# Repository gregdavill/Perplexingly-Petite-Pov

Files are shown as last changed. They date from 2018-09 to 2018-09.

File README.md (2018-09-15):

# Perplexingly-Petite-Pov
A collection of small LED based PCBs.
---

*Current Status: Design Proof of concepts.*

See README of each project to see further details.

---
## idea_001
Based on a Lattice iCE40LP FPGA.
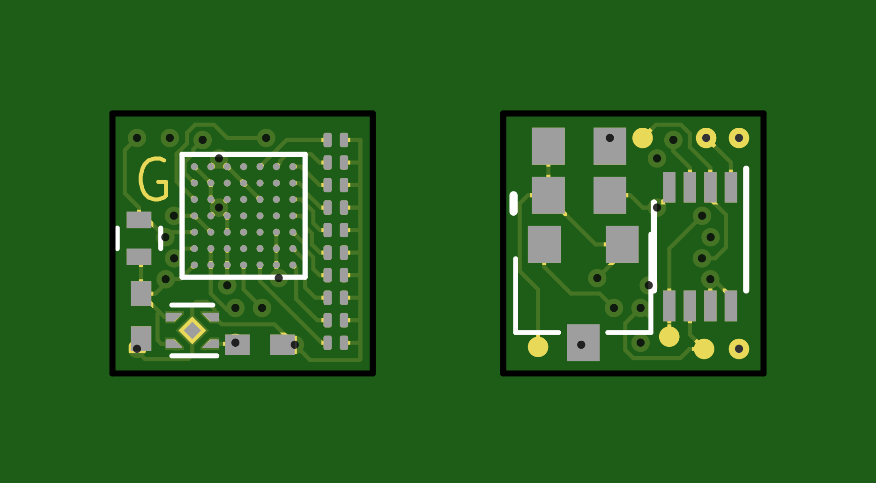
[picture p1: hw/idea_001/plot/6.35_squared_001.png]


## idea_002
Based on a Microchip SAMD11
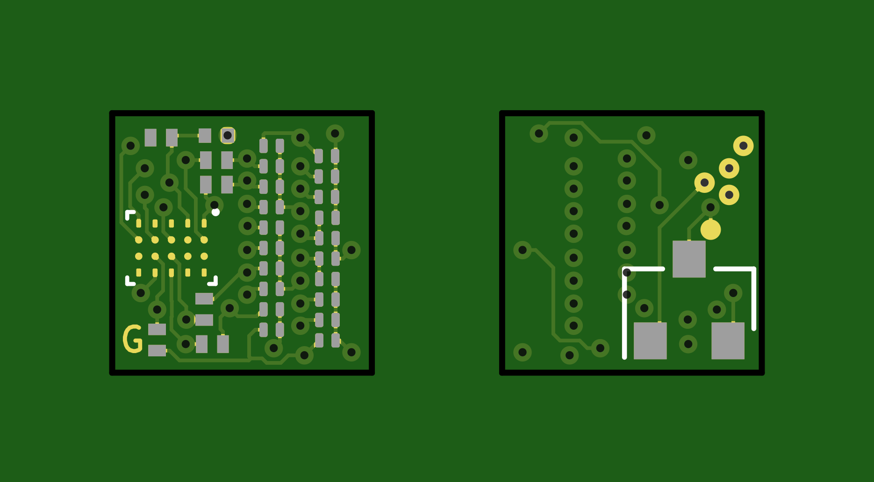
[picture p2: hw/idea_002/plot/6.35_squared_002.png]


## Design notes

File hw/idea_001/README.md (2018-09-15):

# Perplexingly-Petite-Pov
A VERY small FPGA based 10 pixel POV module.
---

*Current Status: Design Proof of concept.*

---
## Board render
PCB render

## Pricipal of Operation

The PCB is intended to be mounted at the edge of a computer fan, it should have all the hardware required to syncronise to the RPM, and keep time, display a rolling text Marquee.

## Hardware
 - Lattice iCE40LP1K FPGA 😍
 - High speed Hall Effect Sensor 😁
 - Configuration FLASH 🤩
 - 16MHz MEMs Oscillator 😎
 - 10x 0201 LEDs 🤪
 - All within a 6.35mm x 6.35mm 4 layer PCB! 😨🤯

## Schematic
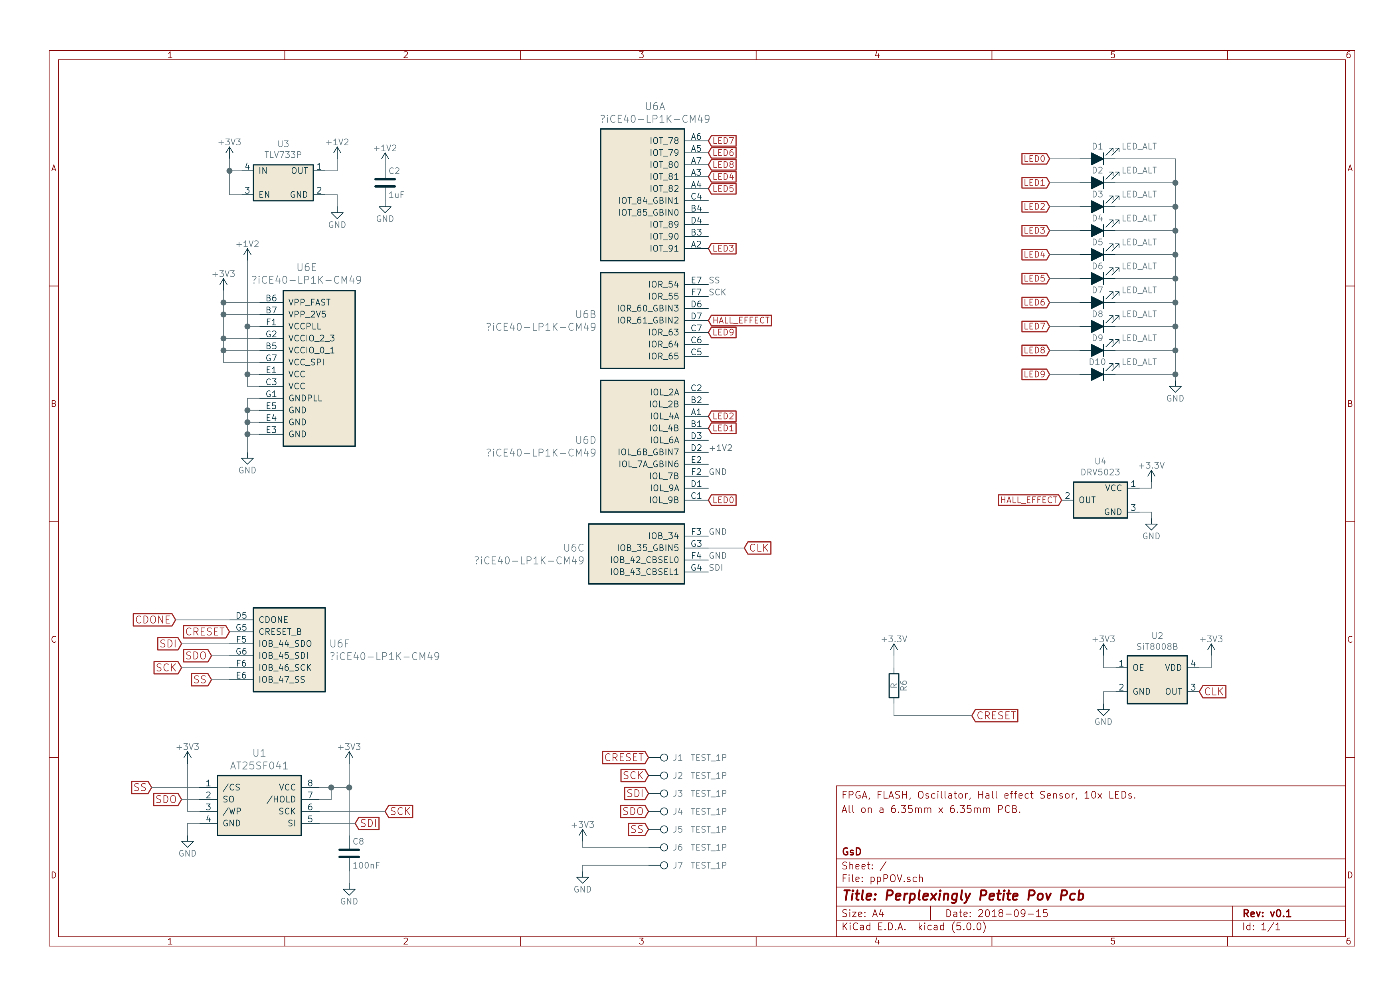
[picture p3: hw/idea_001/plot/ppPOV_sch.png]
Sch


## Firmware

The Firmware has not been written yet, once the hardware is prototyped we can throw this over the cubicle wall to the firmware team.

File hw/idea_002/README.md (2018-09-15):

# Perplexingly-Petite-Pov
A VERY small ARM Microcontroller based 20 pixel POV module.
---

*Current Status: Design Proof of concept.*

---
## Board render
PCB render

## Pricipal of Operation

The PCB is intended to be mounted at the edge of a computer fan, it should have all the hardware required to syncronise to the RPM, and keep time, display a rolling text Marquee.

Ideally the two rows of LEDs will be syncronised to provide a high pixel density. Two colours may be possible, but colud be tricky due to the charliplexing.

## Hardware
 - Microchip ATSAMD11 32bit ARM M0+ 😍
 - High speed Hall Effect Sensor 😁
 - 20x 0201 charliplexed LEDs 🤪
 - All within a 6.35mm x 6.35mm 4 layer PCB! 😨🤯

## Schematic
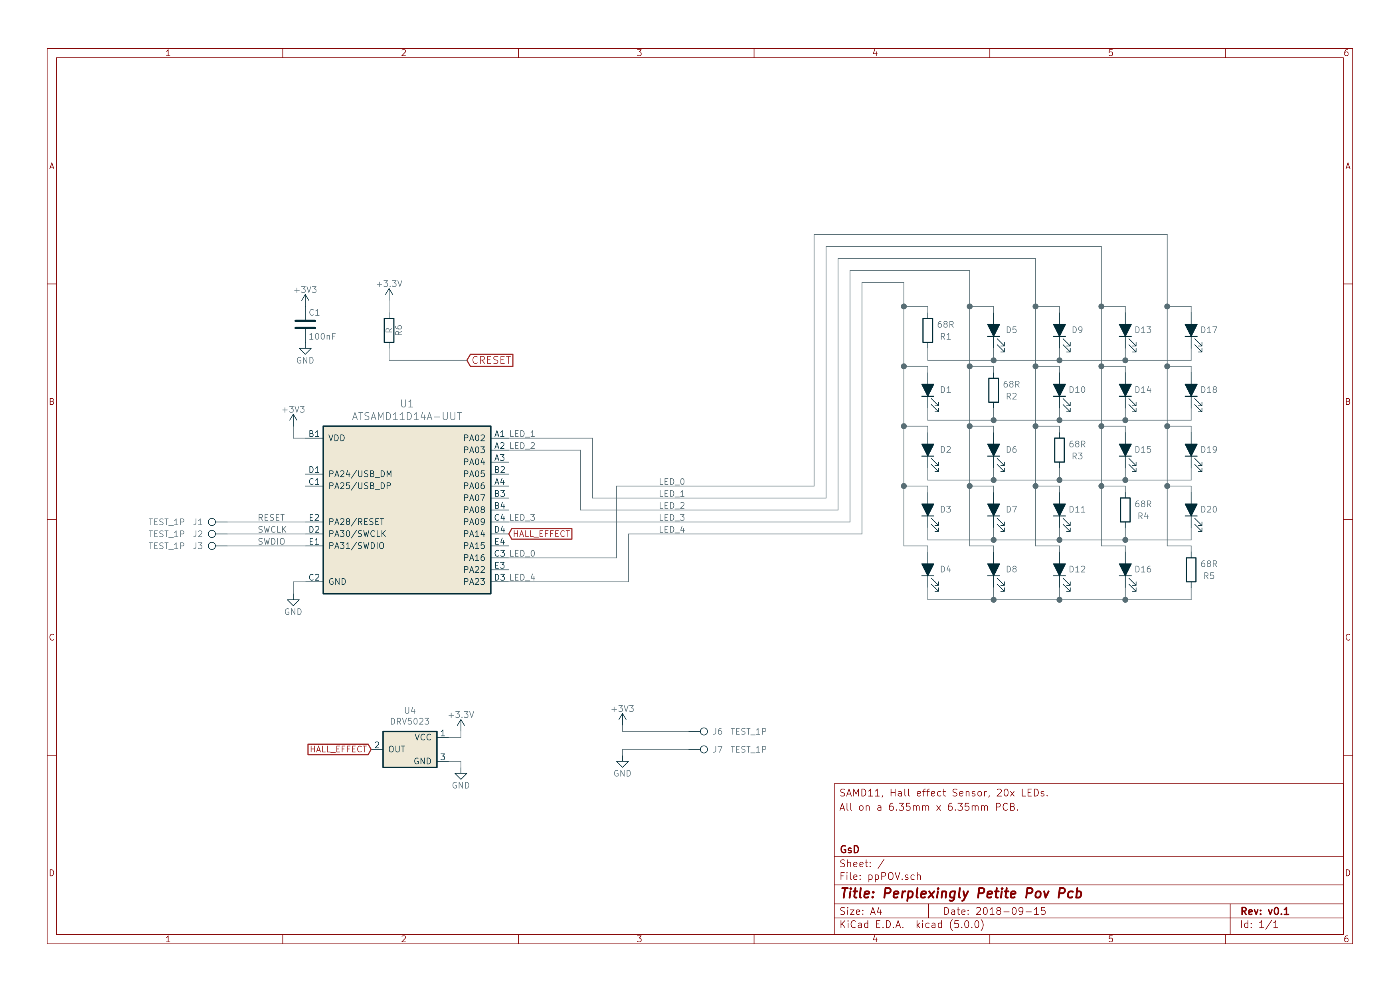
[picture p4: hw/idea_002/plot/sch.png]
Sch


## Firmware

The Firmware has not been written yet, once the hardware is prototyped we can throw this over the cubicle wall to the firmware team. This will likely be running very simple barematel cade, all within a super loop to keep update rates high on the charliplexed display.

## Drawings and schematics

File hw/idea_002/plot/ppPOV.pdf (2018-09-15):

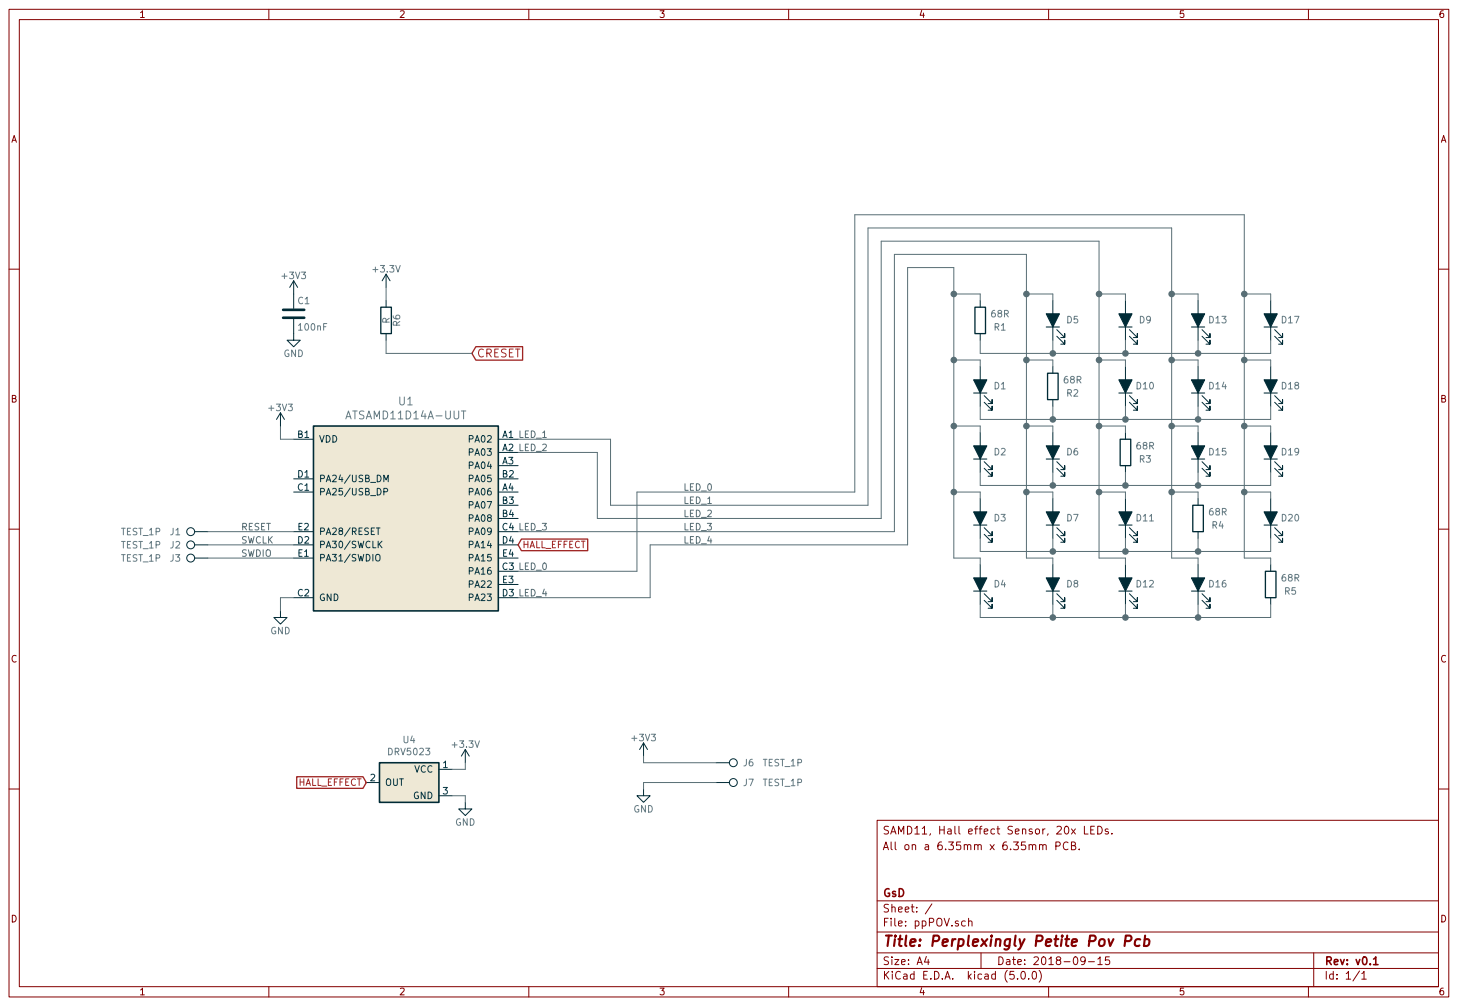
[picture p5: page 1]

RR6 VCC 1 OUT 2 GND 3 U4 DRV5023 GND

All on a 6.35mm x 6.35mm PCB. SAMD11, Hall effect Sensor, 20x LEDs.

File: ppPOV.sch Sheet: / GsD

Id: 1/1 Title: Perplexingly Petite Pov Pcb

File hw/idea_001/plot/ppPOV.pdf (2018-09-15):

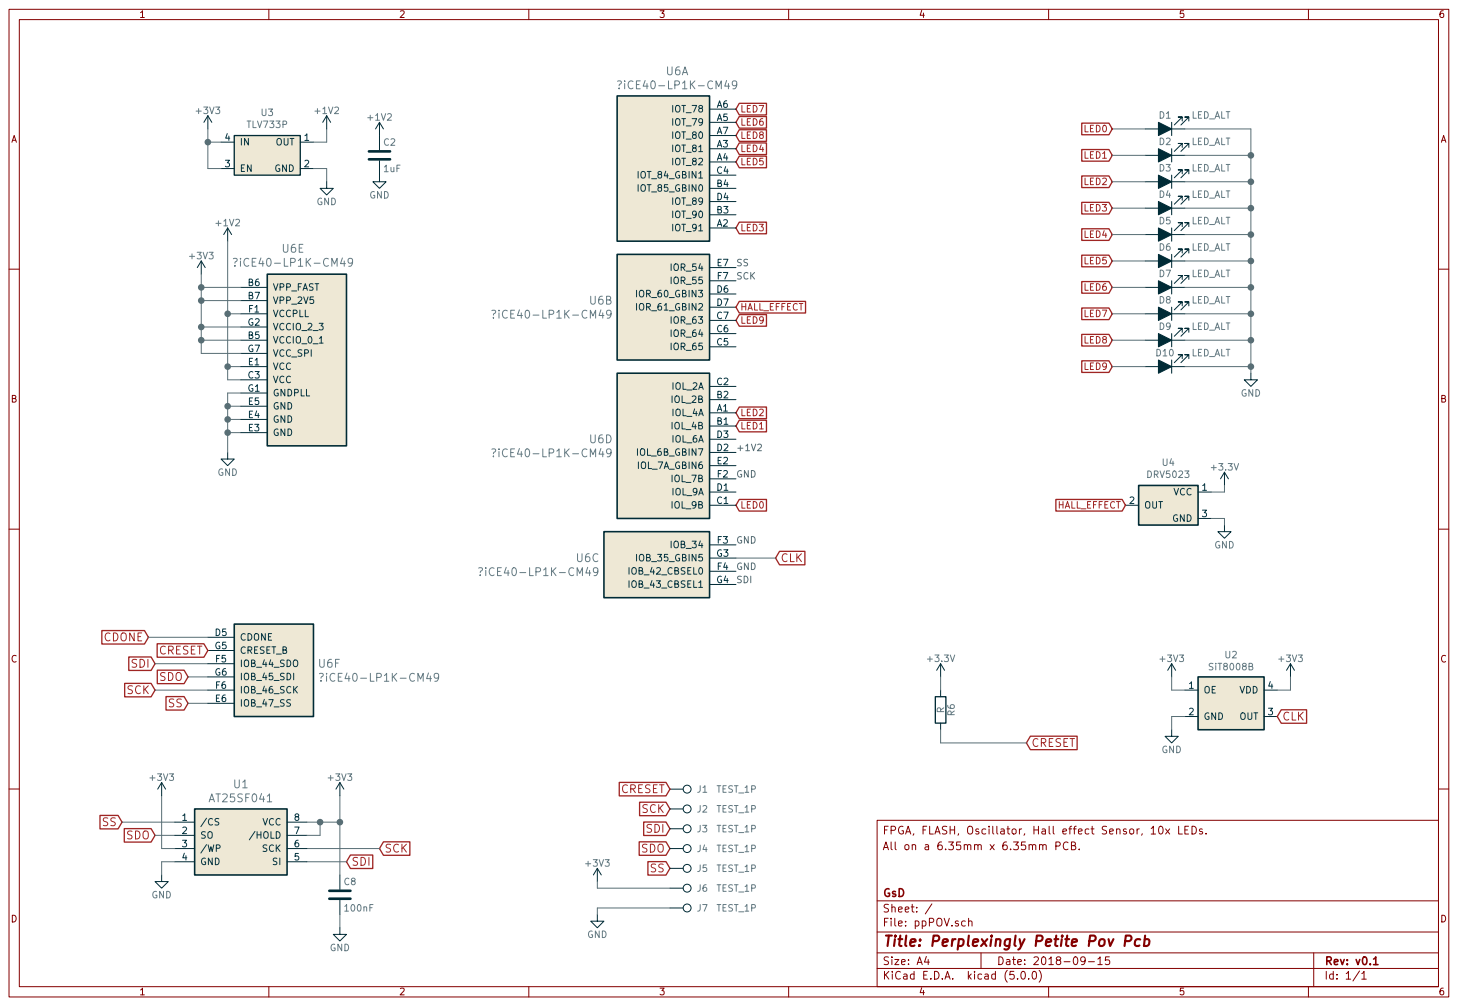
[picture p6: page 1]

All on a 6.35mm x 6.35mm PCB. FPGA, FLASH, Oscillator, Hall effect Sensor, 10x LEDs.

File: ppPOV.sch Sheet: / GsD

Id: 1/1 Title: Perplexingly Petite Pov Pcb

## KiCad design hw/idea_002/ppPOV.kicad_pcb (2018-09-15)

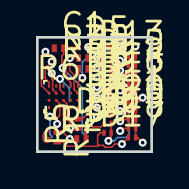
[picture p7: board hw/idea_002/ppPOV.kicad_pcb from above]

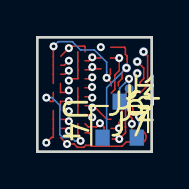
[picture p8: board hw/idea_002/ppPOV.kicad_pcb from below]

Board: 4 copper layers, 6.3 x 6.4 mm, 34 parts (6 on the bottom side), 16 nets.

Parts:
C1: 100nF; C_0201_NoSilk
D1, D2, D3, D4, D5, D6, D7, D8, D9, D10, D11, D12, D13, D14, D15, D16, D17, D18, D19, D20: LED; 0201_led
J1, J2, J3, J6, J7: TEST_1P; Measurement_Point_Round-SMD-Pad_Small
R1, R2, R3, R4, R5: 68R; R_0201_NoSilk
R6: R; R_0201_NoSilk
U1: ATSAMD11D14A-UUT; WLCSP-20_1.93x2.43mm_Pitch0.4mm
U4: DRV5023; SOT-23

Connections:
+3V3: C1.1, J6.1, R6.1, U1.B1, U4.1
/LED_0: D17.2, D18.2, D19.2, D20.2, R5.1, U1.C3
/LED_1: D13.2, D14.2, D15.2, D16.2, R4.1, U1.A1
/LED_2: D9.2, D10.2, D11.2, D12.2, R3.1, U1.A2
/LED_3: D5.2, D6.2, D7.2, D8.2, R2.1, U1.C4
/LED_4: D1.2, D2.2, D3.2, D4.2, R1.1, U1.D3
/RESET: J1.1, U1.E2
/SWCLK: J2.1, U1.D2
/SWDIO: J3.1, U1.E1
GND: C1.2, J7.1, U1.C2, U4.3
HALL_EFFECT: U1.D4, U4.2
unnamed: D1.1, D10.1, D14.1, D18.1, R2.2
unnamed: D3.1, D7.1, D11.1, D20.1, R4.2
unnamed: D4.1, D8.1, D12.1, D16.1, R5.2
unnamed: D5.1, D9.1, D13.1, D17.1, R1.2
unnamed: D2.1, D6.1, D15.1, D19.1, R3.2

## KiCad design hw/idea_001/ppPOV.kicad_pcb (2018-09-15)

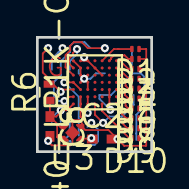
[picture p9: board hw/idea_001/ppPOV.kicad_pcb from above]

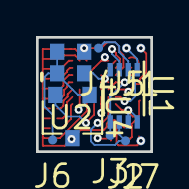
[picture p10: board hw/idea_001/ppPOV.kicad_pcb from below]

Board: 4 copper layers, 6.3 x 6.4 mm, 25 parts (10 on the bottom side), 20 nets.

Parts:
C2: 1uF; C_0402_NoSilk
C8: 100nF; C_0402_NoSilk
D1, D2, D3, D4, D5, D6, D7, D8, D9, D10: LED_ALT; 0201_led
J1, J2, J3, J4, J5, J6, J7: TEST_1P; Measurement_Point_Round-SMD-Pad_Small
R6: R; R_0402
U1: AT25SF041; DFN-8-1EP_3x2mm_Pitch0.5mm
U2: SiT8008B; CDFN3225-4LD-PL-1
U3: TLV733P; TI_X2SON-4_1x1mm_Pitch0.65mm
U4: DRV5023; SC-59
U6:  iCE40-LP1K-CM49; VFBGA-49

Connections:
+1V2: C2.1, U3.1, U6.C3, U6.D2, U6.E1, U6.F1
+3V3: C8.1, J6.1, R6.1, U1.3, U1.7, U1.8, U2.1, U2.4, U3.3, U3.4, U4.1, U6.B5, U6.B6, U6.B7, U6.G2, U6.G7
CLK: U2.3, U6.G3
CRESET: J1.1, R6.2, U6.G5
GND: C2.2, C8.2, D1.1, D2.1, D3.1, D4.1, D5.1, D6.1, D7.1, D8.1, D9.1, D10.1, J7.1, U1.4, U2.2, U3.2, U4.3, U6.E3, U6.E4, U6.E5, U6.F2, U6.F3, U6.F4, U6.G1
HALL_EFFECT: U4.2, U6.D7
LED0: D1.2, U6.C1
LED1: D2.2, U6.B1
LED2: D3.2, U6.A1
LED3: D4.2, U6.A2
LED4: D5.2, U6.A3
LED5: D6.2, U6.A4
LED6: D7.2, U6.A5
LED7: D8.2, U6.A6
LED8: D9.2, U6.A7
LED9: D10.2, U6.C7
SCK: J2.1, U1.6, U6.F6, U6.F7
SDI: J3.1, U1.5, U6.F5, U6.G4
SDO: J4.1, U1.2, U6.G6
SS: J5.1, U1.1, U6.E6, U6.E7

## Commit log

2018-09-15 Initial Commit of KiCad project files.
    [ppPOV.kicad_pcb, ppPOV.sch]
2018-09-15 Updated footprints folder.
2018-09-15 Added schematic to README
2018-09-15 - Spelling corrections. - Added new pcb. ATSAMD11 Based. - Refactored folders to promote reuse.
    [ppPOV.kicad_pcb, ppPOV.sch]
